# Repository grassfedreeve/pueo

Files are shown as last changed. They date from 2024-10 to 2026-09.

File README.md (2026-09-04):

pueo

# pueo
26-key, column-staggered, wireless, reversable, split keyboard made with [ergogen](https://github.com/ergogen/ergogen) and [KiCad](https://www.kicad.org/). Named after the [pueo](https://en.wikipedia.org/wiki/Pueo).

Highly inspired by the [TOTEM](https://github.com/GEIGEIGEIST/TOTEM) by [GEIST](https://github.com/GEIGEIGEIST/), the [zilpzalp](https://github.com/kilipan/zilpzalp), [the berylline](https://github.com/jcmkk3/trochilidae#berylline), and my unibody board the [ʻākohekohe](https://github.com/grassfedreeve/akohekohe/).

Two versions for choc switches are available:
- The default-spacing solder-only version (in the [pcb](https://github.com/grassfedreeve/pueo/tree/main/pcb) directory)
- The minimal-choc-spacing solder-only version with the tightest spacing that choc V1 switches allow for (in the [pcb_min_choc](https://github.com/grassfedreeve/pueo/tree/main/pcb_min_choc) directory)
  **Note:** You will have to procure min-spacing keycaps. I am not aware of any commercial solution. Recommendation: [Philadelphia Minimalist](https://github.com/pseudoku/PseudoMakeMeKeyCapProfiles/blob/master/Philadelphia_Minimalist.scad) by [Pseudoku](https://github.com/pseudoku). There are also currently no 1.5u min-space keycaps, these will need to be generated.

**Warning:** The min-choc-spacing version has not been tested yet!

# Keymap
Example keymap for how you might use this many keys, created using caksoylar's great [keymap-drawer](https://github.com/caksoylar/keymap-drawer)
keymap
Alternative base layouts, Colemak DH, [Bird](https://github.com/jcmkk3/bird-layout), and a Gallium mod shared to me by [ssbb](https://github.com/ssbb) are also great options:
altbase

## BOM
- 2 pcbs
- 2 nice!nanos v2
- 26 kailh choc low profile switches
- 26 keycaps
- 2 100mAh 401230 batteries
- 2 6-pin vertical power switchs such as [these](https://www.amazon.com/dp/B01E3G12YY?)
- 2 [reset buttons TS-1236-4.3](https://www.aliexpress.com/item/1005001629184984.html)]

# Tenting
The pueo was built intending to be used with the great [SpitKB Tenting Puck](https://splitkb.com/products/tenting-puck) and mounted on smallrig magic arms. As of publishing the board they were out of stock so I am using magnetic rings for now.

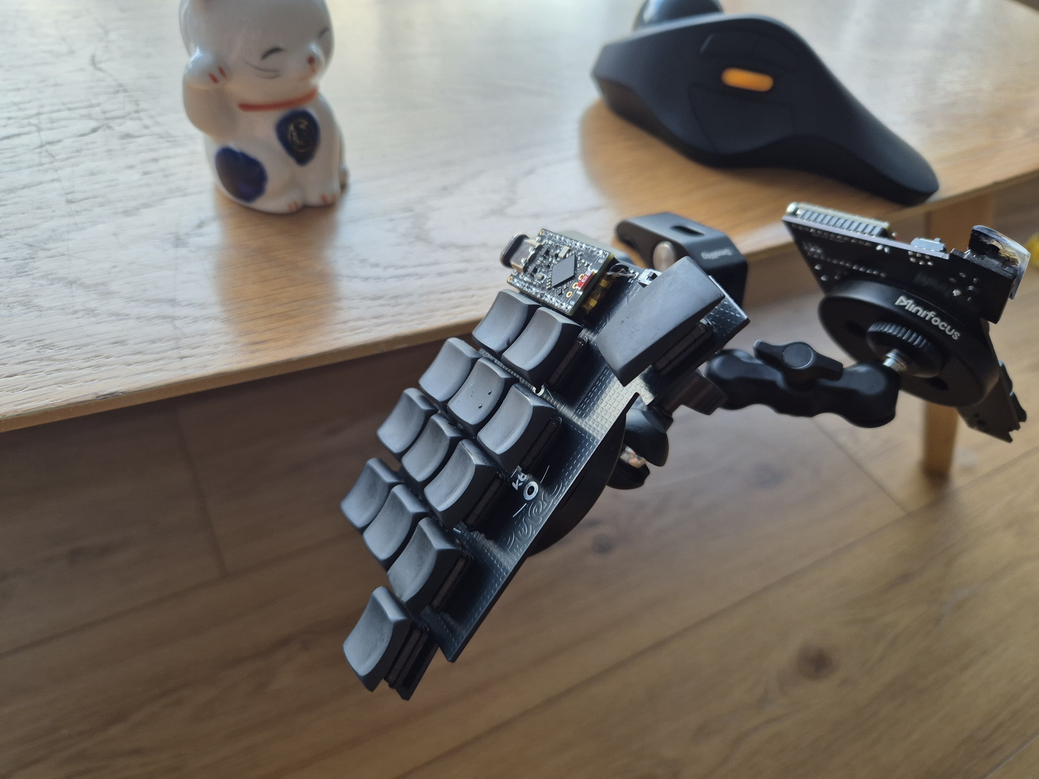
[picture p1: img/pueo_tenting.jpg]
pueo-tenting


## Firmware
ZMK is what I use and have setup a module for: [peuo ZMK Module](https://github.com/grassfedreeve/zmk-keyboards-pueo)

## Inspiration & Thanks
- GEIST's [TOTEM](https://github.com/GEIGEIGEIST/TOTEM) keyboard
- jcmkk3's [berylline](https://github.com/jcmkk3/trochilidae#berylline) and rufous which I based the ergogen config on and used their great footprints.
- apfel's [zilpzalp](https://github.com/kilipan/zilpzalp) keyboard
- PJE66's [hummingbird](https://github.com/PJE66/hummingbird) keyboard
- Weteor's [grumpy](https://github.com/weteor/Grumpy) and [fitis](https://github.com/weteor/fitis)
- apsu's [aptmak](https://github.com/apsu/aptmak) keyboard layout

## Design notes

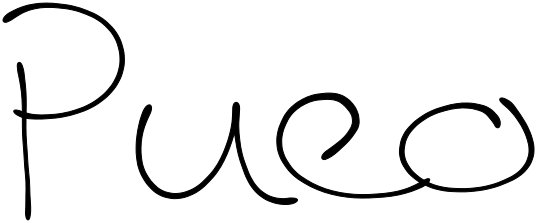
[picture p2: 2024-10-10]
pueo-mx-space/pueo-text.png

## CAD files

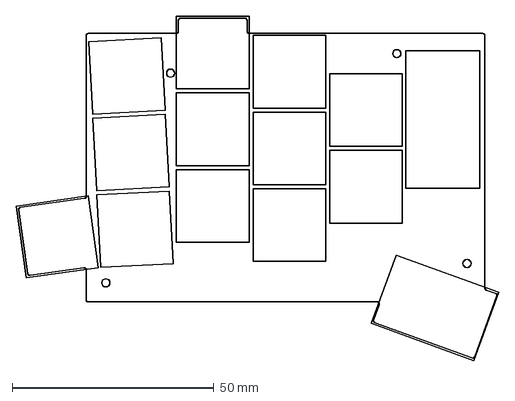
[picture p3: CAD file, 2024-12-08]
pueo-mx-space/output/outlines/demo_keycaps.dxf
119.5 x 85.3 mm

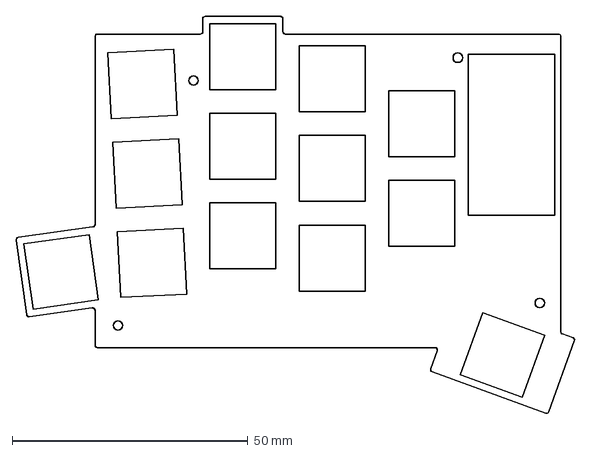
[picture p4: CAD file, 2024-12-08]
pueo-mx-space/output/outlines/demo_switches.dxf
118.5 x 84.2 mm

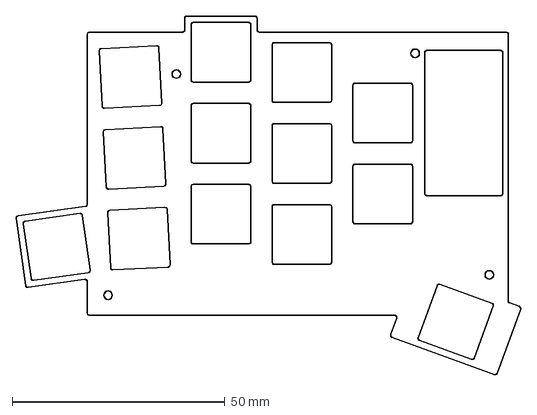
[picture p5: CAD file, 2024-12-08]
pueo-mx-space/output/outlines/switchplate.dxf
118.5 x 84.2 mm

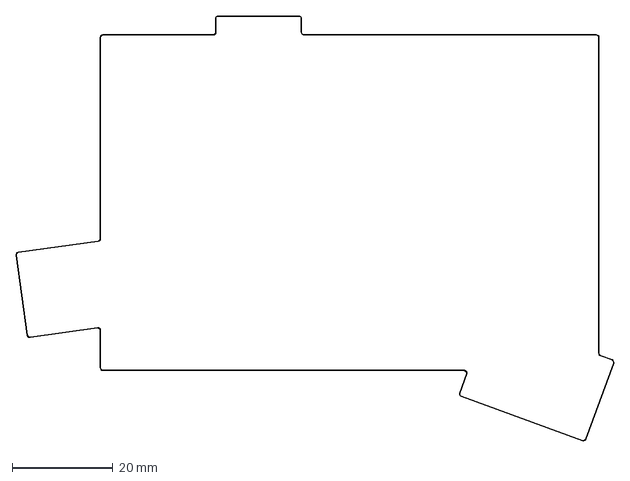
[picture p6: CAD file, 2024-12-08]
pueo-mx-space/output/outlines/panel.dxf
118.5 x 84.2 mm

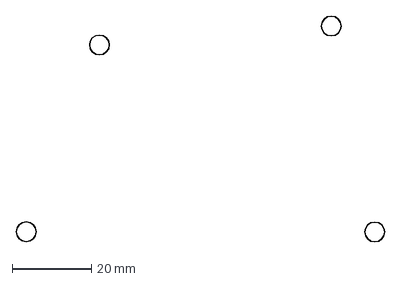
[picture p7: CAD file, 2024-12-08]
pueo-mx-space/output/outlines/standoff.dxf
93.1 x 57.0 mm

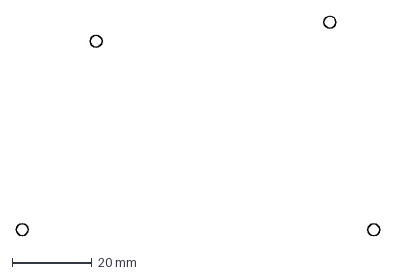
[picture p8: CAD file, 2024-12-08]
pueo-mx-space/output/outlines/mounting.dxf
91.1 x 55.0 mm

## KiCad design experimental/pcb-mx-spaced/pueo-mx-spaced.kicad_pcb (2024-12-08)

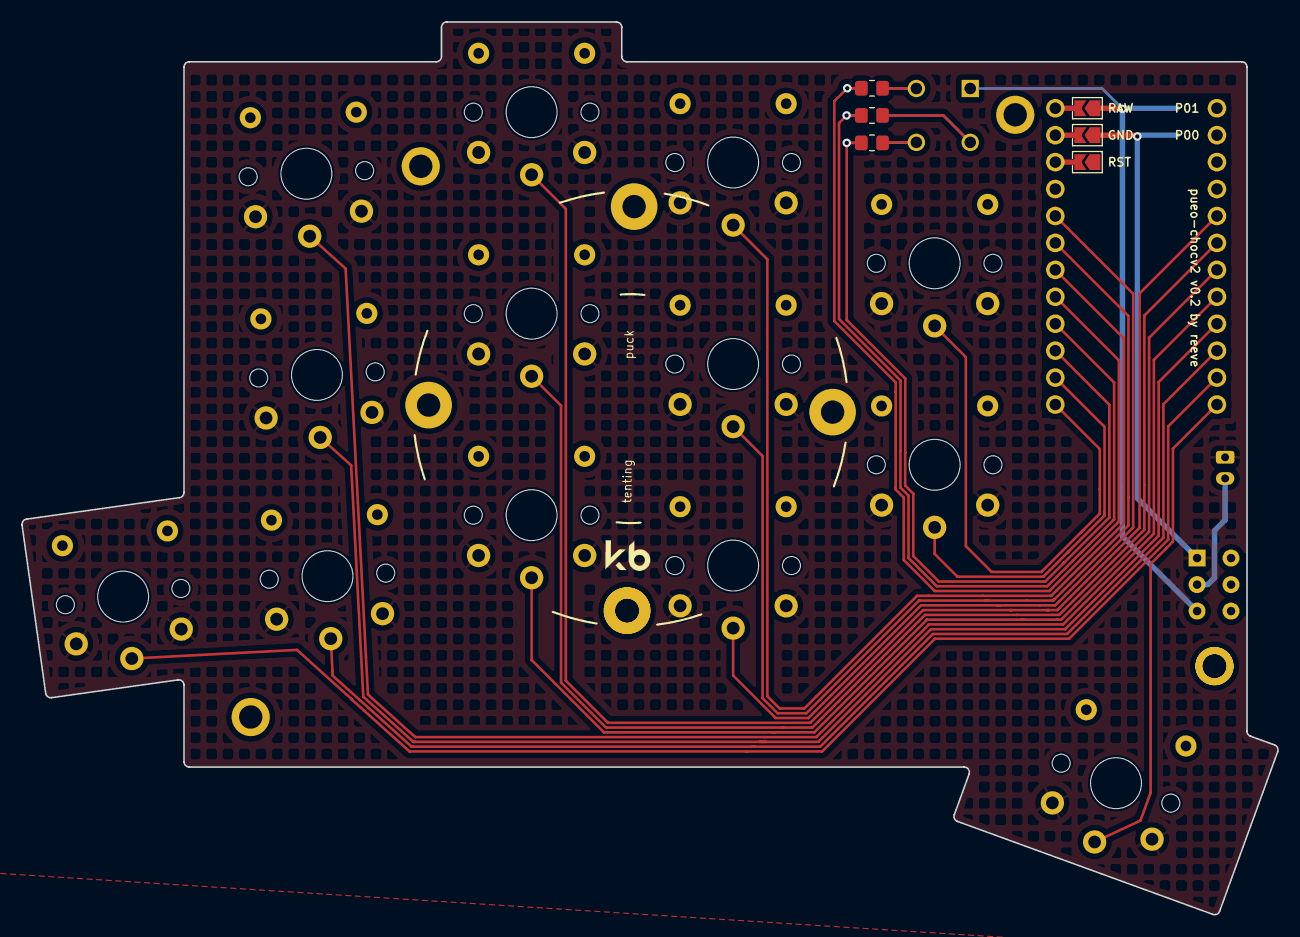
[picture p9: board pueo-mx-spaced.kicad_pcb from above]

Board: 2 copper layers, 118.4 x 84.2 mm, 15 parts (1 on the bottom side), 15 nets.

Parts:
MCU1: ProMicroSimpleJumper
S1, S2, S3, S4, S5, S6, S7, S8, S9, S10, S11, S12, S13: ChocV2SimpleReversible
on/off: SW_E-Switch_EG1271_SPDT

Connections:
GND: MCU1.2, S1.2, S1.3, S2.2, S2.3, S3.2, S3.3, S4.2, S4.3, S5.2, S5.3, S6.2, S6.3, S7.2, S7.3, S8.2, S8.3, S9.2, S9.3, S10.2, S10.3, S11.2, S11.3, S12.2, S12.3, S13.2, S13.3, on/off.1
P2: MCU1.17, S8.1
P3: MCU1.18, S9.1
P4: MCU1.19, S10.1
P8: MCU1.23, S11.1
P9: MCU1.24, S12.1
P10: MCU1.12, S13.1
P14: MCU1.10, S2.1
P15: MCU1.9, S3.1
P16: MCU1.11, S1.1
P18: MCU1.8, S4.1
P19: MCU1.7, S5.1
P20: MCU1.6, S6.1
P21: MCU1.5, S7.1
RAW: MCU1.1, on/off.3

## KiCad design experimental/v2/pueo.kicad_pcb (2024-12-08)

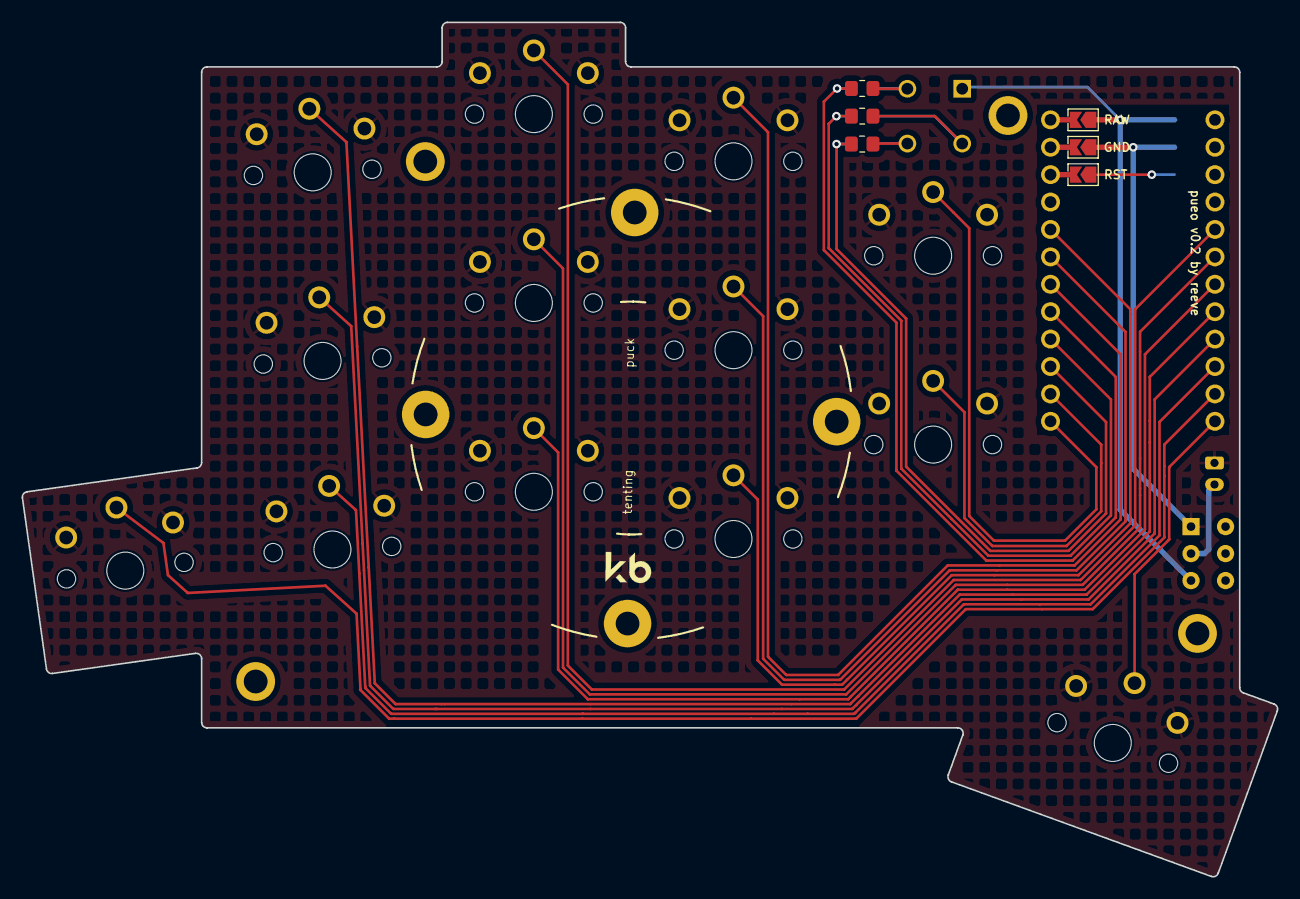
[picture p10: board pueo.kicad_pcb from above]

Board: 2 copper layers, 116.3 x 79.2 mm, 15 parts (1 on the bottom side), 15 nets.

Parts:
MCU1: ProMicroSimpleJumper
S1, S2, S3, S4, S5, S6, S7, S8, S9, S10, S11, S12, S13: ChocSimpleReversible
on/off: SW_E-Switch_EG1271_SPDT

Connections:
GND: MCU1.2, S1.1, S2.1, S3.1, S4.1, S5.1, S6.1, S7.1, S8.1, S9.1, S10.1, S11.1, S12.1, S13.1, on/off.1
P2: MCU1.17, S8.2
P3: MCU1.18, S9.2
P4: MCU1.19, S10.2
P8: MCU1.23, S11.2
P9: MCU1.24, S12.2
P10: MCU1.12, S13.2
P14: MCU1.10, S2.2
P15: MCU1.9, S3.2
P16: MCU1.11, S1.2
P18: MCU1.8, S4.2
P19: MCU1.7, S5.2
P20: MCU1.6, S6.2
P21: MCU1.5, S7.2
RAW: MCU1.1, on/off.3

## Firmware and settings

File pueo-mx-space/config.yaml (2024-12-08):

meta:
  engine: 4.0.0
  name: pueo-mx
  author: grassfedreeve
  url: https://github.com/grassfedreeve/pueo

presets: 
  # These presets provide different layout options
  # Select a preset in the `units` section below
  # Note: The appropriate switch footprint will still need to be set in the `pcb` section
  choc_spaced:
    capx: 17        # Key cap size horizontal
    capy: 16        # Key cap size vertical
    kx: 18.5        # Key spacing horizontal
    ky: 17.5        # Key spacing vertical
    pinky_splay: 5  # Degrees of splay between pinky and ring columns
    pinky_adj: -9   # Adjustment to compensate for splay spacing
    ring_splay: 3
    ring_adj: -8
    middle_splay: 0
    middle_adj: 0
    thumb_offsetx: 0.25kx
  
  choc_min_spaced:
    capx: 14.5
    capy: 14.5
    kx: 15.5
    ky: 15.5
    pinky_splay: 5
    pinky_adj: -3
    ring_splay: 3
    ring_adj: -8
    middle_splay: 3
    middle_adj: -5
    thumb_offsetx: 1/3kx

  mx_spaced:
    capx: 18
    capy: 18
    kx: 19
    ky: 19
    pinky_splay: 5
    pinky_adj: -4
    ring_splay: 3
    ring_adj: -10
    middle_splay: 0
    middle_adj: 0
    thumb_offsetx: 0.25kx
  
  mx_min_spaced:
    capx: 15.5
    capy: 15.5
    kx: 16 + 0.5
    ky: 16 + 0.5
    pinky_splay: 5
    pinky_adj: -3
    ring_splay: 3
    ring_adj: -8
    middle_splay: 3
    middle_adj: -5
    thumb_offsetx: 1/3kx

units:
  $extends: presets.mx_spaced

  # Defaults/Constants
  # ====================
  $default_height: 0  # Points invisible by default unless height/width explicitly set
  $default_width: 0
  xiao_x: 17.8
  xiao_y: 21
  promicro_x: 18.3
  promicro_y: 34.1
  sf: 17


points:
  zones.matrix:
    anchor.shift: [100, -100]  # Fix placement on KiCAD sheet
    rotate: ring_splay + pinky_splay
    key:
      width: capx
      height: capy
      spread: kx      
      padding: ky
      autobind: 0
    rows:
      bottom:
      home:
      top:
    columns.pinky:
      rows:
        bottom.skip: true
        top.skip: true
        home:
          bind: [0ky, 0.5kx, 0, 0]
          row_net: P2
          column_net: P6
    columns.ring:
      key:
        stagger: 0.96ky
        splay: -pinky_splay
        origin: [0, pinky_adj]
      rows:
        bottom:
          bind: [0.5ky, 0, 0, 0]
          row_net: P4
          column_net: P6
        home:
          bind: [0, 0.5kx, 0, 0]
          row_net: P3
          column_net: P6
        top:
          bind: [0, 0.5kx, 0.5ky, 0]
          row_net: P1
          column_net: P6
    columns.middle:
      key:
        stagger: 0.25ky
        splay: -ring_splay
        origin: [0, ring_adj]
      rows:
        bottom:
          bind: [0.5ky, 0.5kx, 0, 0.5kx]
          row_net: P5
          column_net: P6
        home:
          bind: [0, 0.5kx, 0, 0]
          row_net: P2
          column_net: P7
        top:
          bind: [0, 0, 0.5ky, 0]
          row_net: P0
          column_net: P7
    columns.index:
      key.stagger: -0.25ky
      rows:
        bottom:
          bind: [0.5ky, 0, 0, 0]
          row_net: P4
          column_net: P7
        home:
          row_net: P3
          column_net: P7
        top:
          bind: [0, 0, 0.5ky, 0.5kx]
          row_net: P1
          column_net: P7
    columns.inner:
      key.stagger: -0.5ky
      rows:
        bottom.skip: true
        home:
          bind: [0.5ky, 0, 0.5ky, 0.5kx]
          row_net: P2
          column_net: P8
        top:
          bind: [0, 0, 0.5ky, 0.5kx]
          row_net: P0
          column_net: P8
  zones.thumb:
    anchor:
      ref: matrix_index_bottom
      shift: [1.9kx, -0.75ky]
    key.$extends: points.zones.matrix.key
    columns:
      reachy:
        key:
          stagger: -0.33ky
          rotate: -20
          width: 1.5ky        
          bind: [1.5ky, 0, 0, 0]
          row_net: P4
          column_net: P8
  zones.reference_top_center:
    anchor:
      aggregate.parts: [matrix_inner_top]
      shift: [0, -0.65ky]
  zones.reference_index_bottom:
    anchor:
      aggregate.parts: [matrix_index_bottom]
  zones.mcu:
    anchor:
      ref: reference_top_center
      shift: [1kx, 10]
      rotate: -90
    key:
      width: promicro_y
      height: promicro_x
  zones.mounting_hole_top_left:
    anchor:
      - ref: matrix_ring_top
        affect: y
        shift: [0, -0.2ky + 4.5]
      - ref: matrix_ring_top
        affect: x
        shift: [0.7kx - 2.5, 0]
    key:
      height: 2
      width: 2
  zones.mounting_hole_bottom_left:
    anchor:
      - ref: matrix_ring_bottom
        affect: y
        shift: [0, -0.7ky]
      - ref: matrix_ring_bottom
        affect: x
        shift: [-0.25kx - 2.5, 0]
    key:
      height: 2
      width: 2
  zones.mounting_hole_bottom_right:
    anchor:
      - ref: matrix_inner_home
        affect: y
        shift: [0, -1ky]
      - ref: matrix_inner_home
        affect: x
        shift: [1kx + 6, 0]
  zones.mounting_hole_top_right:
    anchor:
      - ref: matrix_inner_home
        affect: y
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
